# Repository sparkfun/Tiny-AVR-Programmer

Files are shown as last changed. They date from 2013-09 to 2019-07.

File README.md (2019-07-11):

Tiny AVR Programmer
===================

Tiny AVR Programmer

[*Tiny AVR Programmer (PGM-11801)*](https://www.sparkfun.com/products/11801)

The Tiny AVR Programmer plugs directly into your USB port and provides a programming socket for the ATtiny45 and 85.

This was a collaboration with David Mellis and the MIT High Low Tech lab. 
See [Programming an ATtiny with Arduino 1.0](http://hlt.media.mit.edu/?p=1695) 
and [Using the TinyProgrammer](http://hlt.media.mit.edu/?p=1801) for more drivers and additional information.

Repository Contents
-------------------
* **/Drivers** - Signed drivers for the Tiny AVR Programmer
* **/Hardware** - Eagle design files (.brd, .sch)
* **/Production** - Production panel files (.brd)

Documentation
--------------
* **[Hookup Guide](https://learn.sparkfun.com/tutorials/tiny-avr-programmer-hookup-guide/)** - Basic hookup guide for the Programmer.
* **[SparkFun Fritzing repo](https://github.com/sparkfun/Fritzing_Parts)** - Fritzing diagrams for SparkFun products.
* **[SparkFun 3D Model repo](https://github.com/sparkfun/3D_Models)** - 3D models of SparkFun products. 

License Information
-------------------

This product is _**open source**_! 

Please review the LICENSE.md file for license information. 

If you have any questions or concerns on licensing, please visit the [SparkFun Forum](https://forum.sparkfun.com/index.php) and post a topic. For more general questions related to our programmers, please visit this section of the forum: [SparkFun Forums: PROGRAMMERS](https://forum.sparkfun.com/viewforum.php?f=104).

Distributed as-is; no warranty is given.
- Your friends at SparkFun.

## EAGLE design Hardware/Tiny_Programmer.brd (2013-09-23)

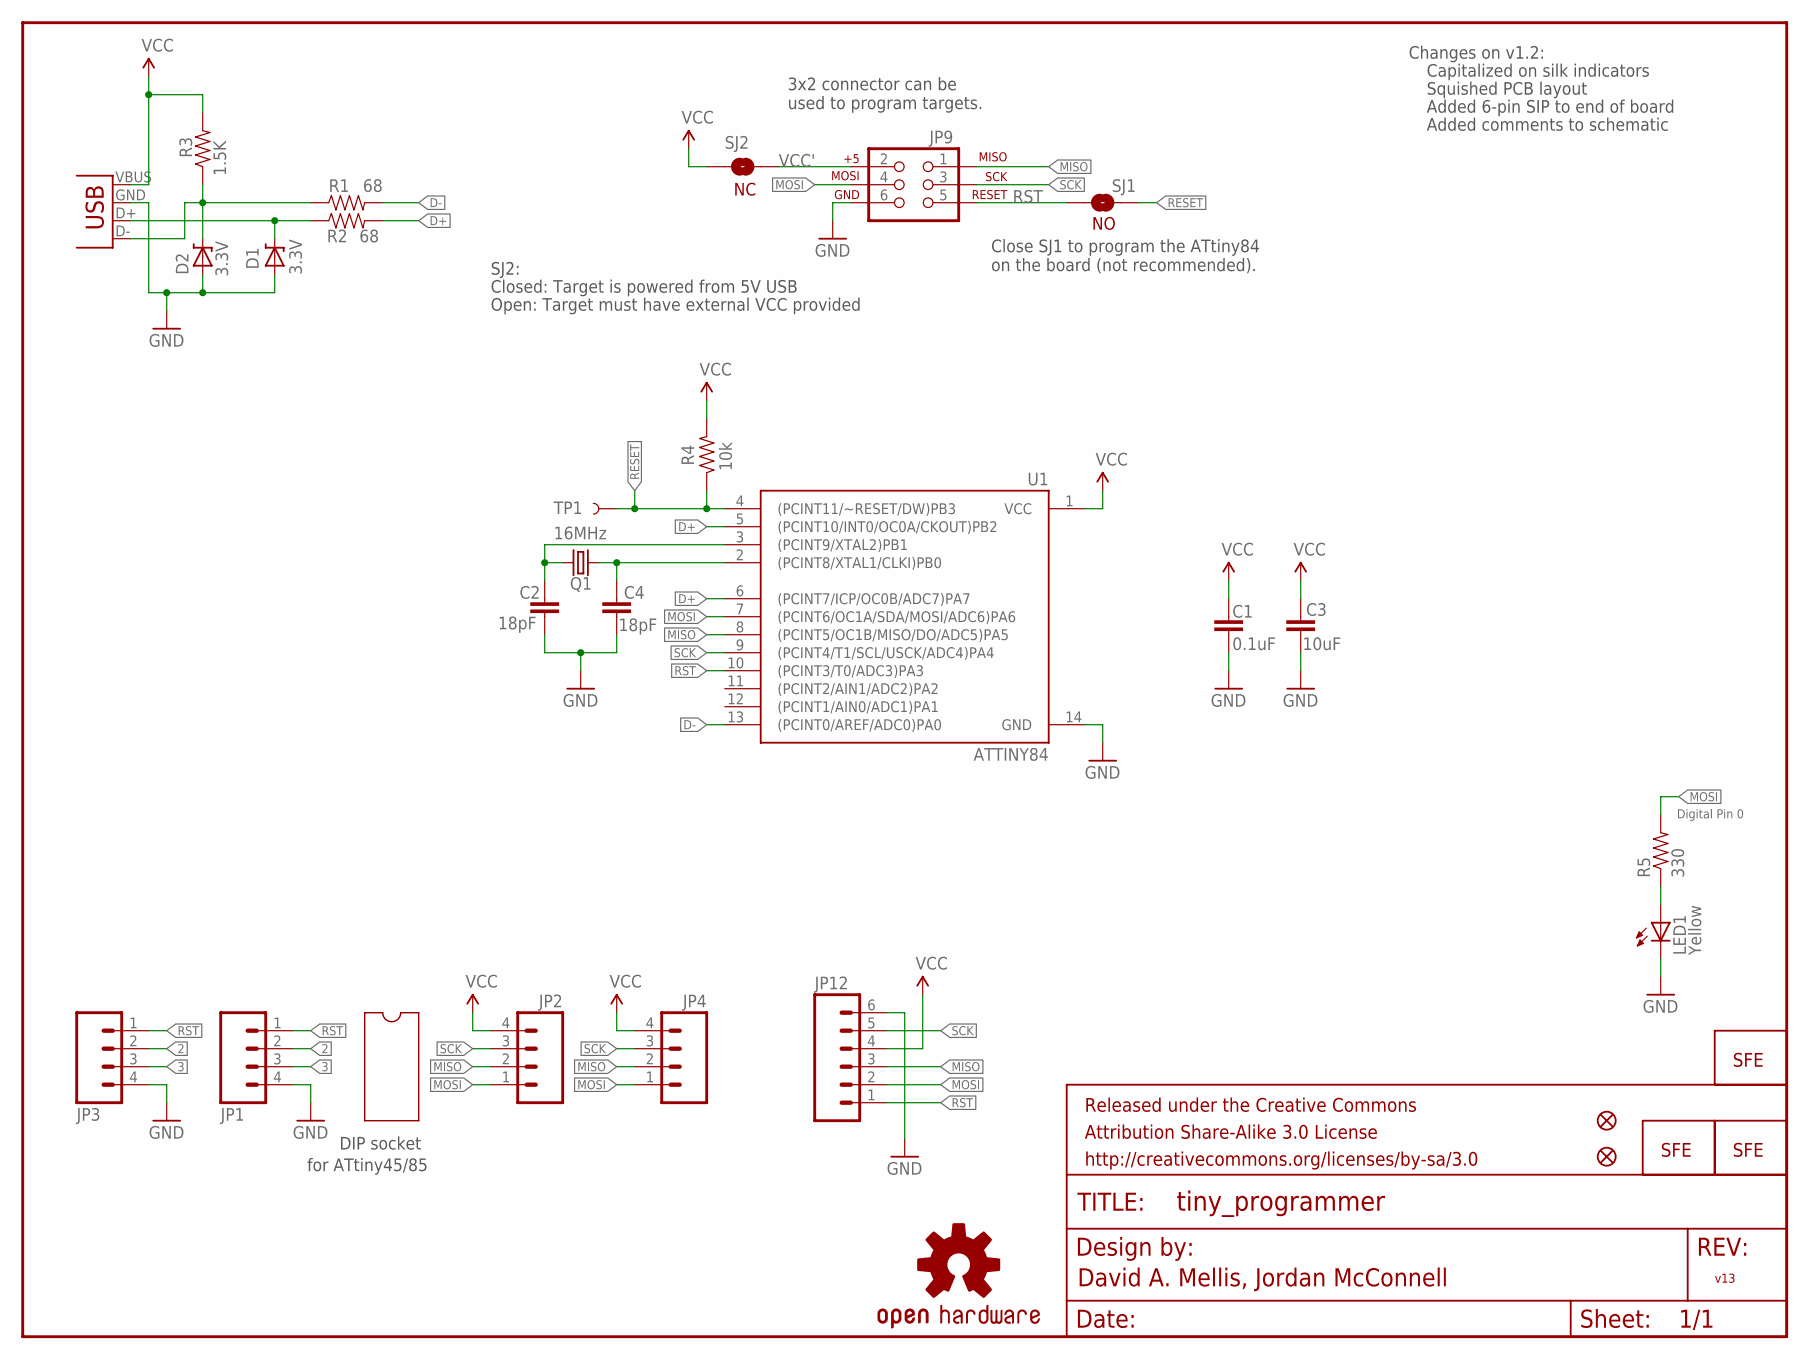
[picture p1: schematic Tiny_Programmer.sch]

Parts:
C1: 0.1uF; 0402-CAP
C2, C4: 18pF; 0402-CAP
C3: 10uF; 0402-CAP
D1, D2: 3.3V; SOD-323
FRAME1: FRAME-LETTER; CREATIVE_COMMONS
JP1, JP2: M04PTH; 1X04
JP3, JP4: M04SMD_STRAIGHT_COMBO; 1X04_SMD_STRAIGHT_COMBO
JP5: LOGO-SFENW2; SFE-NEW-WEB
JP6, JP11: LOGO-SFESK; SFE-LOGO-FLAME
JP7, JP8: FIDUCIALUFIDUCIAL; MICRO-FIDUCIAL
JP9: AVR_SPI_PRG_6PTH; 2X3
JP12: M06SIP; 1X06
LED1: Yellow; LED-0603
Q1: 16MHz; CRYSTAL-SMD-5X3
R1, R2: 68; 0402-RES
R3: 1.5K; 0402-RES
R4: 10k; 0402-RES
R5: 330; 0402-RES
SJ1: SOLDERJUMPERNO; SJ_2S-NO
SJ2: NC; SJ_2S
TP1: TEST-POINT3; PAD.03X.03
U1: ATTINY84; SO14
U$1: OSHW-LOGOS; OSHW-LOGO-S
X1: USB-A-H

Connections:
2: JP1.2, JP3.2
3: JP1.3, JP3.3
D+: R2.2, U1.5 ((PCINT10/INT0/OC0A/CKOUT)PB2), U1.6 ((PCINT7/ICP/OC0B/ADC7)PA7)
D-: R1.2, U1.13 ((PCINT0/AREF/ADC0)PA0)
GND: C1.2, C2.2, C3.2, C4.2, D1.2 (A), D2.2 (A), JP1.4, JP3.4, JP9.6, JP12.6, LED1.C, U1.14 (GND), X1.GND (VBUS)
MISO: JP2.2, JP4.2, JP9.1, JP12.3, U1.8 ((PCINT5/OC1B/MISO/DO/ADC5)PA5)
MOSI: JP2.1, JP4.1, JP9.4, JP12.2, R5.2, U1.7 ((PCINT6/OC1A/SDA/MOSI/ADC6)PA6)
unnamed: D2.1 (C), R1.1, R3.1, X1.D- (D+)
unnamed: D1.1 (C), R2.1, X1.D+ (D-)
unnamed: C2.1, Q1.3 (2), U1.3 ((PCINT9/XTAL2)PB1)
unnamed: C4.1, Q1.1, U1.2 ((PCINT8/XTAL1/CLKI)PB0)
unnamed: LED1.A, R5.1
RESET: R4.1, SJ1.1, TP1.P$1, U1.4 ((PCINT11/~RESET/DW)PB3)
RST: JP1.1, JP3.1, JP9.5, JP12.1, SJ1.2, U1.10 ((PCINT3/T0/ADC3)PA3)
SCK: JP2.3, JP4.3, JP9.3, JP12.5, U1.9 ((PCINT4/T1/SCL/USCK/ADC4)PA4)
VCC: C1.1, C3.1, JP2.4, JP4.4, JP12.4, R3.2, R4.2, SJ2.1, U1.1 (VCC), X1.VBUS (GND)
VCC': JP9.2, SJ2.2

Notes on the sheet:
David A. Mellis, Jordan McConnell
Digital Pin 0
Changes on v1.2:
Capitalized on silk indicators
DIP socket
for ATtiny45/85
3x2 connector can be used to program targets.
Close SJ1 to program the ATtiny84 on the board (not recommended).
Closed: Target is powered from 5V USB
Open: Target must have external VCC provided
SJ2:
Squished PCB layout
Added 6-pin SIP to end of board
Added comments to schematic
v13

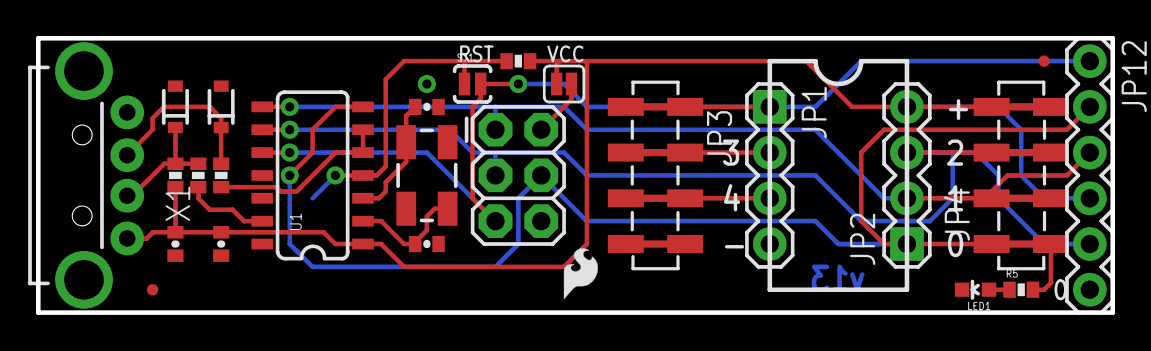
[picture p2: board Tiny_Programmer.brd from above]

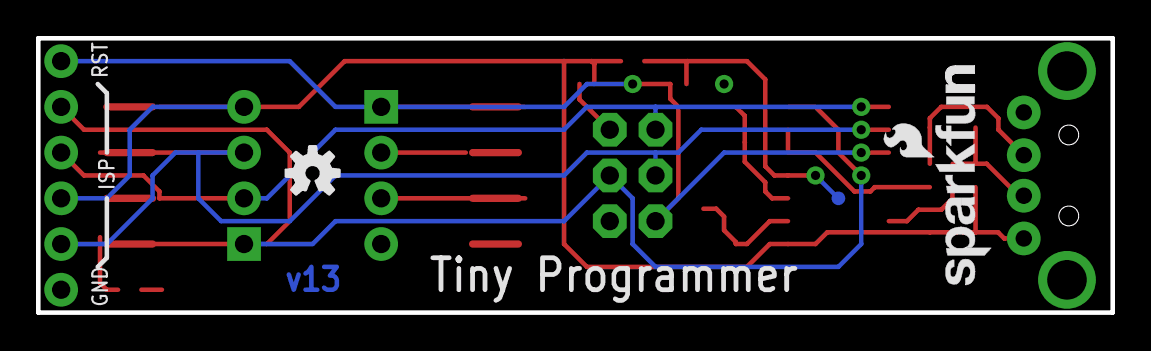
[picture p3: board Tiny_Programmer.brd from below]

Board: 2 copper layers, 59.7 x 15.2 mm, 31 parts (4 on the bottom side), 17 nets.

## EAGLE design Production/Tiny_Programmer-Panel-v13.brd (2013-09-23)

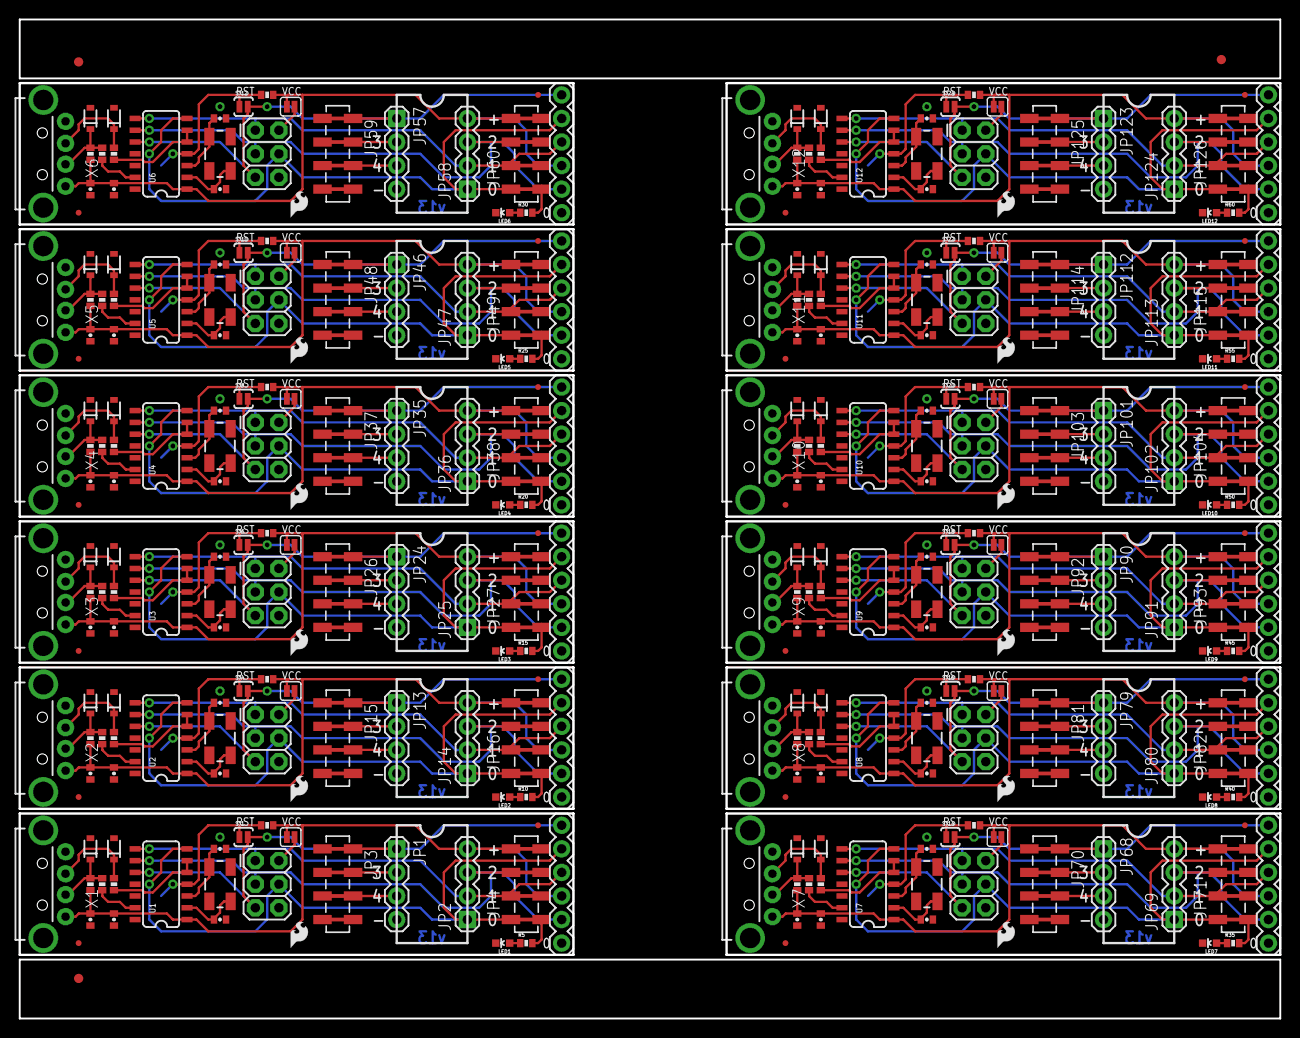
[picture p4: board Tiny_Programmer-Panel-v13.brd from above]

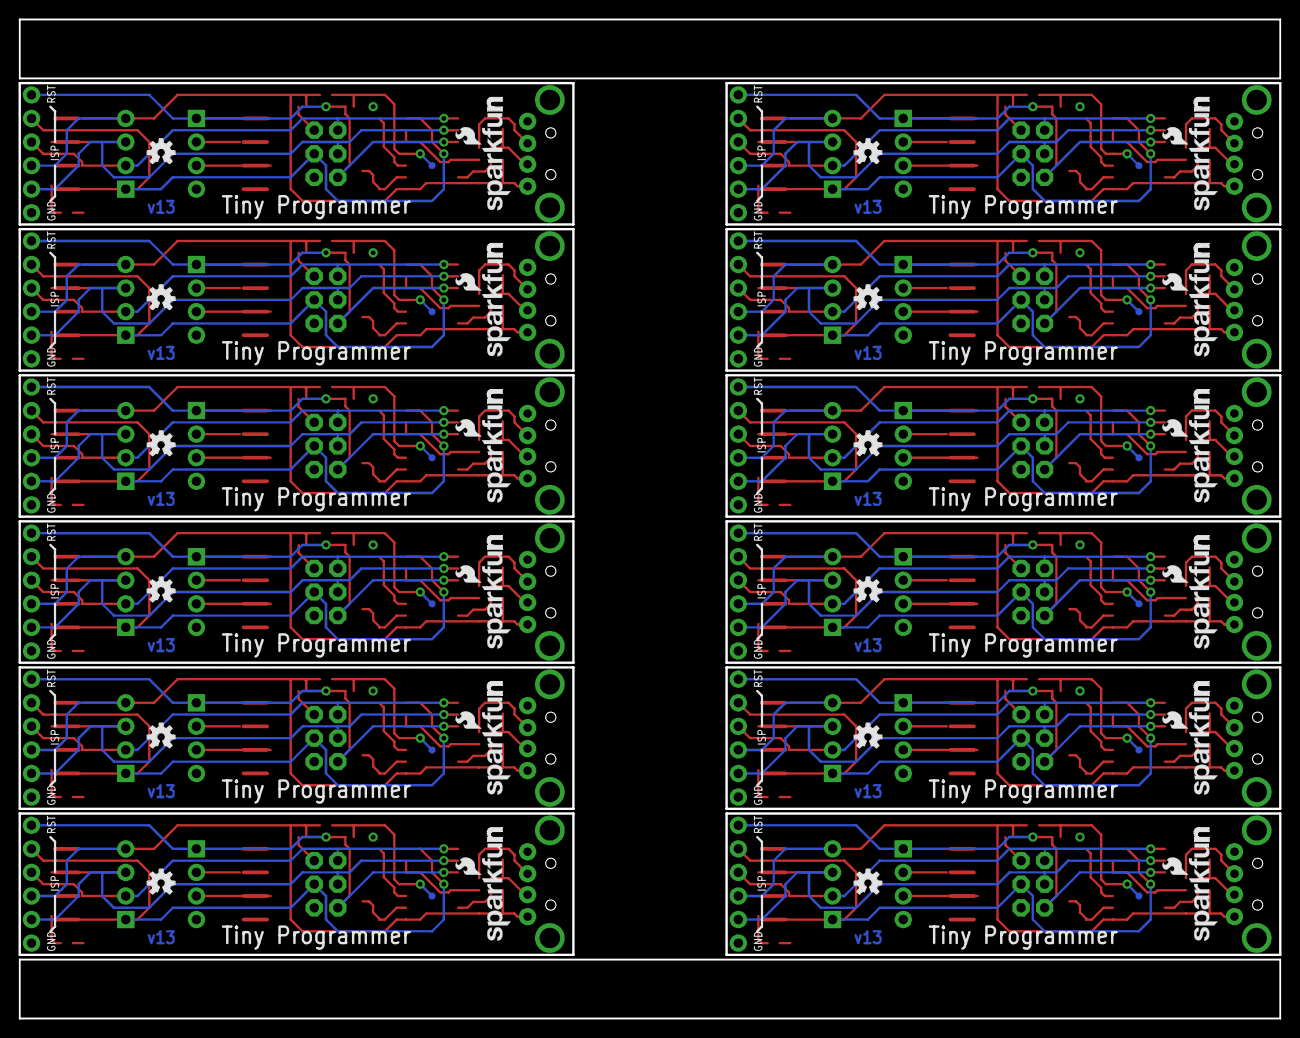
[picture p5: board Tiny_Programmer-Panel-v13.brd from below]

Board: 2 copper layers, 135.9 x 107.7 mm, 363 parts (48 on the bottom side), 204 nets.

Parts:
C1, C5, C9, C13, C17, C21, C25, C29, C33, C37, C41, C45: 0.1uF; 0402-CAP
C2, C4, C7, C8, C11, C12, C15, C16, C19, C20, C23, C24, C27, C28, C31, C32, C35, C36, C39, C40, C43, C44, C47, C48: 18pF; 0402-CAP
C3, C6, C10, C14, C18, C22, C26, C30, C34, C38, C42, C46: 10uF; 0402-CAP
D1, D2, D3, D4, D5, D6, D7, D8, D9, D10, D11, D12, D13, D14, D15, D16, D17, D18, D19, D20, D21, D22, D23, D24: 3.3V; SOD-323
E$1, E$3, E$4: FIDUCIAL-1X2
JP1, JP2, JP13, JP14, JP24, JP25, JP35, JP36, JP46, JP47, JP57, JP58, JP68, JP69, JP79, JP80, JP90, JP91, JP101, JP102, JP112, JP113, JP123, JP124: 1X04
JP3, JP4, JP15, JP16, JP26, JP27, JP37, JP38, JP48, JP49, JP59, JP60, JP70, JP71, JP81, JP82, JP92, JP93, JP103, JP104, JP114, JP115, JP125, JP126: 1X04_SMD_STRAIGHT_COMBO
JP5, JP17, JP28, JP39, JP50, JP61, JP72, JP83, JP94, JP105, JP116, JP127: LOGO-SFENW2; SFE-NEW-WEB
JP6, JP11, JP18, JP21, JP29, JP32, JP40, JP43, JP51, JP54, JP62, JP65, JP73, JP76, JP84, JP87, JP95, JP98, JP106, JP109, JP117, JP120, JP128, JP131: LOGO-SFESK; SFE-LOGO-FLAME
JP7, JP8, JP19, JP20, JP30, JP31, JP41, JP42, JP52, JP53, JP63, JP64, JP74, JP75, JP85, JP86, JP96, JP97, JP107, JP108, JP118, JP119, JP129, JP130: FIDUCIALUFIDUCIAL; MICRO-FIDUCIAL
JP9, JP10, JP23, JP34, JP45, JP56, JP67, JP78, JP89, JP100, JP111, JP122: 2X3
JP12, JP22, JP33, JP44, JP55, JP66, JP77, JP88, JP99, JP110, JP121, JP132: 1X06
LED1, LED2, LED3, LED4, LED5, LED6, LED7, LED8, LED9, LED10, LED11, LED12: Yellow; LED-0603
Q1, Q2, Q3, Q4, Q5, Q6, Q7, Q8, Q9, Q10, Q11, Q12: 16MHz; CRYSTAL-SMD-5X3
R1, R2, R6, R7, R11, R12, R16, R17, R21, R22, R26, R27, R31, R32, R36, R37, R41, R42, R46, R47, R51, R52, R56, R57: 68; 0402-RES
R3, R8, R13, R18, R23, R28, R33, R38, R43, R48, R53, R58: 1.5K; 0402-RES
R4, R9, R14, R19, R24, R29, R34, R39, R44, R49, R54, R59: 10k; 0402-RES
R5, R10, R15, R20, R25, R30, R35, R40, R45, R50, R55, R60: 330; 0402-RES
SJ1, SJ4, SJ6, SJ8, SJ10, SJ12, SJ14, SJ16, SJ18, SJ20, SJ22, SJ24: SOLDERJUMPERNO; SJ_2S-NO
SJ2, SJ3, SJ5, SJ7, SJ9, SJ11, SJ13, SJ15, SJ17, SJ19, SJ21, SJ23: NC; SJ_2S
TP1, TP2, TP3, TP4, TP5, TP6, TP7, TP8, TP9, TP10, TP11, TP12: TEST-POINT3; PAD.03X.03
U1, U2, U3, U4, U5, U6, U7, U8, U9, U10, U11, U12: ATTINY84; SO14
U$1, U$2, U$3, U$4, U$5, U$6, U$7, U$8, U$9, U$10, U$11, U$12: OSHW-LOGOS; OSHW-LOGO-S
X1, X2, X3, X4, X5, X6, X7, X8, X9, X10, X11, X12: USB-A-H

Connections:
1: JP13.3, JP15.3
2: JP1.2, JP3.2
3: JP1.3, JP3.3
4: JP13.2, JP15.2
5: JP24.3, JP26.3
6: JP24.2, JP26.2
7: JP35.3, JP37.3
8: JP35.2, JP37.2
9: JP46.3, JP48.3
10: JP46.2, JP48.2
11: JP57.3, JP59.3
12: JP57.2, JP59.2
13: JP68.3, JP70.3
14: JP68.2, JP70.2
15: JP79.3, JP81.3
16: JP79.2, JP81.2
17: JP90.3, JP92.3
18: JP90.2, JP92.2
19: JP101.3, JP103.3
20: JP101.2, JP103.2
21: JP112.3, JP114.3
22: JP112.2, JP114.2
23: JP123.3, JP125.3
24: JP123.2, JP125.2
D+: R2.2, U1.5, U1.6
D+1: R7.2, U2.5, U2.6
D+2: R12.2, U3.5, U3.6
D+3: R17.2, U4.5, U4.6
D+4: R22.2, U5.5, U5.6
D+5: R27.2, U6.5, U6.6
D+6: R32.2, U7.5, U7.6
D+7: R37.2, U8.5, U8.6
D+8: R42.2, U9.5, U9.6
D+9: R47.2, U10.5, U10.6
D+10: R52.2, U11.5, U11.6
D+11: R57.2, U12.5, U12.6
D-: R1.2, U1.13
D-1: R6.2, U2.13
D-2: R11.2, U3.13
D-3: R16.2, U4.13
D-4: R21.2, U5.13
D-5: R26.2, U6.13
D-6: R31.2, U7.13
D-7: R36.2, U8.13
D-8: R41.2, U9.13
D-9: R46.2, U10.13
D-10: R51.2, U11.13
D-11: R56.2, U12.13
GND: C1.2, C2.2, C3.2, C4.2, D1.2, D2.2, JP1.4, JP3.4, JP9.6, JP12.6, LED1.C, U1.14, X1.GND
GND1: C5.2, C6.2, C7.2, C8.2, D3.2, D4.2, JP10.6, JP13.4, JP15.4, JP22.6, LED2.C, U2.14, X2.GND
GND2: C9.2, C10.2, C11.2, C12.2, D5.2, D6.2, JP23.6, JP24.4, JP26.4, JP33.6, LED3.C, U3.14, X3.GND
GND3: C13.2, C14.2, C15.2, C16.2, D7.2, D8.2, JP34.6, JP35.4, JP37.4, JP44.6, LED4.C, U4.14, X4.GND
GND4: C17.2, C18.2, C19.2, C20.2, D9.2, D10.2, JP45.6, JP46.4, JP48.4, JP55.6, LED5.C, U5.14, X5.GND
GND5: C21.2, C22.2, C23.2, C24.2, D11.2, D12.2, JP56.6, JP57.4, JP59.4, JP66.6, LED6.C, U6.14, X6.GND
GND6: C25.2, C26.2, C27.2, C28.2, D13.2, D14.2, JP67.6, JP68.4, JP70.4, JP77.6, LED7.C, U7.14, X7.GND
GND7: C29.2, C30.2, C31.2, C32.2, D15.2, D16.2, JP78.6, JP79.4, JP81.4, JP88.6, LED8.C, U8.14, X8.GND
GND8: C33.2, C34.2, C35.2, C36.2, D17.2, D18.2, JP89.6, JP90.4, JP92.4, JP99.6, LED9.C, U9.14, X9.GND
GND9: C37.2, C38.2, C39.2, C40.2, D19.2, D20.2, JP100.6, JP101.4, JP103.4, JP110.6, LED10.C, U10.14, X10.GND
GND10: C41.2, C42.2, C43.2, C44.2, D21.2, D22.2, JP111.6, JP112.4, JP114.4, JP121.6, LED11.C, U11.14, X11.GND
GND11: C45.2, C46.2, C47.2, C48.2, D23.2, D24.2, JP122.6, JP123.4, JP125.4, JP132.6, LED12.C, U12.14, X12.GND
MISO: JP2.2, JP4.2, JP9.1, JP12.3, U1.8
MISO1: JP10.1, JP14.2, JP16.2, JP22.3, U2.8
MISO2: JP23.1, JP25.2, JP27.2, JP33.3, U3.8
MISO3: JP34.1, JP36.2, JP38.2, JP44.3, U4.8
MISO4: JP45.1, JP47.2, JP49.2, JP55.3, U5.8
MISO5: JP56.1, JP58.2, JP60.2, JP66.3, U6.8
MISO6: JP67.1, JP69.2, JP71.2, JP77.3, U7.8
MISO7: JP78.1, JP80.2, JP82.2, JP88.3, U8.8
MISO8: JP89.1, JP91.2, JP93.2, JP99.3, U9.8
MISO9: JP100.1, JP102.2, JP104.2, JP110.3, U10.8
MISO10: JP111.1, JP113.2, JP115.2, JP121.3, U11.8
MISO11: JP122.1, JP124.2, JP126.2, JP132.3, U12.8
MOSI: JP2.1, JP4.1, JP9.4, JP12.2, R5.2, U1.7
MOSI1: JP10.4, JP14.1, JP16.1, JP22.2, R10.2, U2.7
MOSI2: JP23.4, JP25.1, JP27.1, JP33.2, R15.2, U3.7
MOSI3: JP34.4, JP36.1, JP38.1, JP44.2, R20.2, U4.7
MOSI4: JP45.4, JP47.1, JP49.1, JP55.2, R25.2, U5.7
MOSI5: JP56.4, JP58.1, JP60.1, JP66.2, R30.2, U6.7
MOSI6: JP67.4, JP69.1, JP71.1, JP77.2, R35.2, U7.7
MOSI7: JP78.4, JP80.1, JP82.1, JP88.2, R40.2, U8.7
MOSI8: JP89.4, JP91.1, JP93.1, JP99.2, R45.2, U9.7
MOSI9: JP100.4, JP102.1, JP104.1, JP110.2, R50.2, U10.7
MOSI10: JP111.4, JP113.1, JP115.1, JP121.2, R55.2, U11.7
MOSI11: JP122.4, JP124.1, JP126.1, JP132.2, R60.2, U12.7
unnamed: D2.1, R1.1, R3.1, X1.D-
unnamed: D1.1, R2.1, X1.D+
unnamed: C2.1, Q1.3, U1.3
unnamed: C4.1, Q1.1, U1.2
unnamed: LED1.A, R5.1
unnamed: D4.1, R6.1, R8.1, X2.D-
unnamed: D3.1, R7.1, X2.D+
unnamed: C7.1, Q2.3, U2.3
unnamed: C8.1, Q2.1, U2.2
unnamed: LED2.A, R10.1
unnamed: D6.1, R11.1, R13.1, X3.D-
unnamed: D5.1, R12.1, X3.D+
unnamed: C11.1, Q3.3, U3.3
unnamed: C12.1, Q3.1, U3.2
unnamed: LED3.A, R15.1
unnamed: D8.1, R16.1, R18.1, X4.D-
unnamed: D7.1, R17.1, X4.D+
unnamed: C15.1, Q4.3, U4.3
unnamed: C16.1, Q4.1, U4.2
unnamed: LED4.A, R20.1
unnamed: D10.1, R21.1, R23.1, X5.D-
unnamed: D9.1, R22.1, X5.D+
unnamed: C19.1, Q5.3, U5.3
unnamed: C20.1, Q5.1, U5.2
unnamed: LED5.A, R25.1
unnamed: D12.1, R26.1, R28.1, X6.D-
unnamed: D11.1, R27.1, X6.D+
unnamed: C23.1, Q6.3, U6.3
unnamed: C24.1, Q6.1, U6.2
unnamed: LED6.A, R30.1
unnamed: D14.1, R31.1, R33.1, X7.D-
unnamed: D13.1, R32.1, X7.D+
unnamed: C27.1, Q7.3, U7.3
unnamed: C28.1, Q7.1, U7.2
unnamed: LED7.A, R35.1
unnamed: D16.1, R36.1, R38.1, X8.D-
unnamed: D15.1, R37.1, X8.D+
unnamed: C31.1, Q8.3, U8.3
unnamed: C32.1, Q8.1, U8.2
unnamed: LED8.A, R40.1
unnamed: D18.1, R41.1, R43.1, X9.D-
unnamed: D17.1, R42.1, X9.D+
unnamed: C35.1, Q9.3, U9.3
unnamed: C36.1, Q9.1, U9.2
unnamed: LED9.A, R45.1
unnamed: D20.1, R46.1, R48.1, X10.D-
unnamed: D19.1, R47.1, X10.D+
unnamed: C39.1, Q10.3, U10.3
unnamed: C40.1, Q10.1, U10.2
unnamed: LED10.A, R50.1
unnamed: D22.1, R51.1, R53.1, X11.D-
unnamed: D21.1, R52.1, X11.D+
unnamed: C43.1, Q11.3, U11.3
unnamed: C44.1, Q11.1, U11.2
unnamed: LED11.A, R55.1
unnamed: D24.1, R56.1, R58.1, X12.D-
unnamed: D23.1, R57.1, X12.D+
unnamed: C47.1, Q12.3, U12.3
unnamed: C48.1, Q12.1, U12.2
unnamed: LED12.A, R60.1
RESET: R4.1, SJ1.1, TP1.P$1, U1.4
RESET1: R9.1, SJ4.1, TP2.P$1, U2.4
RESET2: R14.1, SJ6.1, TP3.P$1, U3.4
RESET3: R19.1, SJ8.1, TP4.P$1, U4.4
RESET4: R24.1, SJ10.1, TP5.P$1, U5.4
RESET5: R29.1, SJ12.1, TP6.P$1, U6.4
RESET6: R34.1, SJ14.1, TP7.P$1, U7.4
RESET7: R39.1, SJ16.1, TP8.P$1, U8.4
RESET8: R44.1, SJ18.1, TP9.P$1, U9.4
RESET9: R49.1, SJ20.1, TP10.P$1, U10.4
RESET10: R54.1, SJ22.1, TP11.P$1, U11.4
RESET11: R59.1, SJ24.1, TP12.P$1, U12.4
RST: JP1.1, JP3.1, JP9.5, JP12.1, SJ1.2, U1.10
RST1: JP10.5, JP13.1, JP15.1, JP22.1, SJ4.2, U2.10
RST2: JP23.5, JP24.1, JP26.1, JP33.1, SJ6.2, U3.10
RST3: JP34.5, JP35.1, JP37.1, JP44.1, SJ8.2, U4.10
RST4: JP45.5, JP46.1, JP48.1, JP55.1, SJ10.2, U5.10
RST5: JP56.5, JP57.1, JP59.1, JP66.1, SJ12.2, U6.10
RST6: JP67.5, JP68.1, JP70.1, JP77.1, SJ14.2, U7.10
RST7: JP78.5, JP79.1, JP81.1, JP88.1, SJ16.2, U8.10
RST8: JP89.5, JP90.1, JP92.1, JP99.1, SJ18.2, U9.10
RST9: JP100.5, JP101.1, JP103.1, JP110.1, SJ20.2, U10.10
RST10: JP111.5, JP112.1, JP114.1, JP121.1, SJ22.2, U11.10
RST11: JP122.5, JP123.1, JP125.1, JP132.1, SJ24.2, U12.10
SCK: JP2.3, JP4.3, JP9.3, JP12.5, U1.9
SCK1: JP10.3, JP14.3, JP16.3, JP22.5, U2.9
SCK2: JP23.3, JP25.3, JP27.3, JP33.5, U3.9
SCK3: JP34.3, JP36.3, JP38.3, JP44.5, U4.9
SCK4: JP45.3, JP47.3, JP49.3, JP55.5, U5.9
SCK5: JP56.3, JP58.3, JP60.3, JP66.5, U6.9
SCK6: JP67.3, JP69.3, JP71.3, JP77.5, U7.9
SCK7: JP78.3, JP80.3, JP82.3, JP88.5, U8.9
SCK8: JP89.3, JP91.3, JP93.3, JP99.5, U9.9
SCK9: JP100.3, JP102.3, JP104.3, JP110.5, U10.9
SCK10: JP111.3, JP113.3, JP115.3, JP121.5, U11.9
SCK11: JP122.3, JP124.3, JP126.3, JP132.5, U12.9
VCC: C1.1, C3.1, JP2.4, JP4.4, JP12.4, R3.2, R4.2, SJ2.1, U1.1, X1.VBUS
VCC1: C5.1, C6.1, JP14.4, JP16.4, JP22.4, R8.2, R9.2, SJ3.1, U2.1, X2.VBUS
VCC2: C9.1, C10.1, JP25.4, JP27.4, JP33.4, R13.2, R14.2, SJ5.1, U3.1, X3.VBUS
VCC3: C13.1, C14.1, JP36.4, JP38.4, JP44.4, R18.2, R19.2, SJ7.1, U4.1, X4.VBUS
VCC4: C17.1, C18.1, JP47.4, JP49.4, JP55.4, R23.2, R24.2, SJ9.1, U5.1, X5.VBUS
VCC5: C21.1, C22.1, JP58.4, JP60.4, JP66.4, R28.2, R29.2, SJ11.1, U6.1, X6.VBUS
VCC6: C25.1, C26.1, JP69.4, JP71.4, JP77.4, R33.2, R34.2, SJ13.1, U7.1, X7.VBUS
VCC7: C29.1, C30.1, JP80.4, JP82.4, JP88.4, R38.2, R39.2, SJ15.1, U8.1, X8.VBUS
VCC8: C33.1, C34.1, JP91.4, JP93.4, JP99.4, R43.2, R44.2, SJ17.1, U9.1, X9.VBUS
VCC9: C37.1, C38.1, JP102.4, JP104.4, JP110.4, R48.2, R49.2, SJ19.1, U10.1, X10.VBUS
VCC10: C41.1, C42.1, JP113.4, JP115.4, JP121.4, R53.2, R54.2, SJ21.1, U11.1, X11.VBUS
VCC11: C45.1, C46.1, JP124.4, JP126.4, JP132.4, R58.2, R59.2, SJ23.1, U12.1, X12.VBUS
VCC': JP9.2, SJ2.2
VCC'1: JP10.2, SJ3.2
VCC'2: JP23.2, SJ5.2
VCC'3: JP34.2, SJ7.2
VCC'4: JP45.2, SJ9.2
VCC'5: JP56.2, SJ11.2
VCC'6: JP67.2, SJ13.2
VCC'7: JP78.2, SJ15.2
VCC'8: JP89.2, SJ17.2
VCC'9: JP100.2, SJ19.2
VCC'10: JP111.2, SJ21.2
VCC'11: JP122.2, SJ23.2

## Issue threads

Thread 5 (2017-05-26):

Windows 10

xRootbeer21, 2017-05-26:
Razer Blade Stealth Laptop, OS:  Windows 10.0.14393, x64-Based PC. After downloading a zip (from here) and extracting, the driver installer for both x64 and x82 did not work. Running it with administrator privileges did not work. Troubleshooting by running it in one of the older versions of Windows in Compatibility Mode did not help in the slightest. Neither did using a clone from the Github desktop work. The window would open for just a split-second and then close. When reopening the installer rapidly, the title "installer...exe" was visible, but no other text, just a white window. Ultimately, I was unable to get a driver installed by searching for it manually in device manager without that installer working.
However, I was able to get the driver from an Adafruit Driver Installer application, which can be found here: https://learn.adafruit.com/usbtinyisp/drivers
And a few short minutes later I had some code working on an Attiny45 and breadboard!

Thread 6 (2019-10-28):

showing up as FabISP on mac

bmoren, 2019-10-28:
Anyone else having issues on mac?

Tested on
10.13.4 // via USB hub / USBC dongle
with Crosspack  avrdude

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

bboyho, 2020-05-28:
Hi,

Sorry for the delay in reply. I noticed this question when browsing our issues.

**Renaming USB Device**

I'm not sure if this is really an issue? Depending on what is installed with an OS, the device may show up as "**FabISP**" but it should still function as an AVR programmer.  I've seen this happen on a Windows OS. I was still able to flash an AVR chip as long as I selected "**USBtinyISP**" as the programmer via the Arduino IDE or using "**usbtiny**" for AVRDUDE's programmer type via command line. To adjust the name, I used "[Zadig](https://learn.sparkfun.com/tutorials/tiny-avr-programmer-hookup-guide#automatic-install)". It looks like that software is only for Windows.

If you really want to rename the device on a Mac, there may be a way. I am not sure the exact details on adjusting the name. Most forums suggest that you are not able to change the USB device name. However, there was one forum that indicated you may be able to rename the attached USB device by using an "alias" and writing a bash script to make it permanent. You may have to adjust the permissions to enable the script.

**Issues Flashing an AVR Chip**

If I had any issues flashing an AVR chip, I simply uninstalled the device using the Window's Device Manager and reinstalled with Zadig. If there are issues flashing an AVR chip, you may need to take additional troubleshooting steps. It looks like your AVR programmer is already on a USB 2.0 hub, so you probably have not seen any issues flashing an AVR chip.

**Still Having Issues?**

If you still have issues, you may want to check out the following forums for further assistance or methods:

* [SparkFun Forums](https://forum.sparkfun.com/)
* [Arduino Forums](https://forum.arduino.cc/)
* [Arduino Stack Exchange](https://arduino.stackexchange.com/)

Closed 2020-05-28.

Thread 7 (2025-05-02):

Fails to install driver on Windows 11

scarolan, 2025-05-02:
I'm using a Surface Pro 11, it has an ARM processor.  Could this be why it doesn't work?

I tried the Zadig software, installing the drivers directly, both fail.

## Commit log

2013-04-03 Pushed v1.2 of board. Added 6-pin SIP to edge of board.
    General PCB squishing. Not sure if the edge-mount USB will have enough
    room near the mounting holes. Need to run proto.
    [Tiny Programmer_PB.brd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]
2013-04-03 Updated comments on schematic.
    [Tiny_Programmer_v12.sch]
2013-04-17 Going to new conventions.
    Remove extra eagle backup files. Remove version from eagle files (let
    github do versioning). Moved test bed files into production folder.
    [Tiny Programmer_PB.brd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]
2013-09-23 Modifies the new 6-pin SIP to be more compatible with an FTDI.
    The new pin out should allow MOSI and MISO to bit-bang serial and
    communicate over an FTDI connection for serial debuggin.
    [Tiny_Programmer.brd, Tiny_Programmer.sch]
2013-09-23 Panel Created
    Panel created in Production folder, Panels folder...
    [Tiny_Programmer-Panel-v13.brd]
2013-09-26 Revert "Panel Created"
    This reverts commit 09fbf32834caab243eb0e1dba20c0eff250af01e.
    [Tiny_Programmer-Panel-v13.brd]
2013-09-26 Revert "Modifies the new 6-pin SIP to be more compatible with an FTDI."
    This reverts commit e9ce5eee6c851359ce4a9d7fdec24ce809564be4.
    [Tiny_Programmer.brd, Tiny_Programmer.sch]
2015-08-27 Added signed Windows drivers
2015-11-23 Adding version number to schematic
    [Tiny_Programmer.sch]

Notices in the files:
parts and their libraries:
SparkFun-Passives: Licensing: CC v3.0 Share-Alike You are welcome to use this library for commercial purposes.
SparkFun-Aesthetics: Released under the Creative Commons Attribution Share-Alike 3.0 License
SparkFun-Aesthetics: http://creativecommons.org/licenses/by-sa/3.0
